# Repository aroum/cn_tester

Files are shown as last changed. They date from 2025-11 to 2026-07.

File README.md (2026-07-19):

# c!n tester: ProMicro-like Microcontroller Tester

## 🚀 Project Overview

The **c!n tester** is a dedicated hardware and software solution designed for automated functional testing of ProMicro-like microcontrollers (MCUs). Its primary goal is to provide a fast and reliable way to verify basic pin connectivity and functionality before deployment.

### 🚧 Current Status: Work In Progress (WIP)

The core testing logic and fundamental functionality are fully operational. However, active development is focused on improving the GUI and enhancing the overall user experience.

> [!IMPORTANT]
> **Bug Reports & Logging:**
> * **Any bug reports must be accompanied by logs.** Reports without logs cannot be diagnosed and will be closed.
> * **How to access logs:** Inside the GUI, click on the **USB connector image** at the center of the pinout visualization. This will open the log view showing real-time console outputs for both Master and Target MCUs.
> * If the application fails to start entirely, look for the `app_error.log` file created in the same directory as the executable.

## 🧱 Hardware System

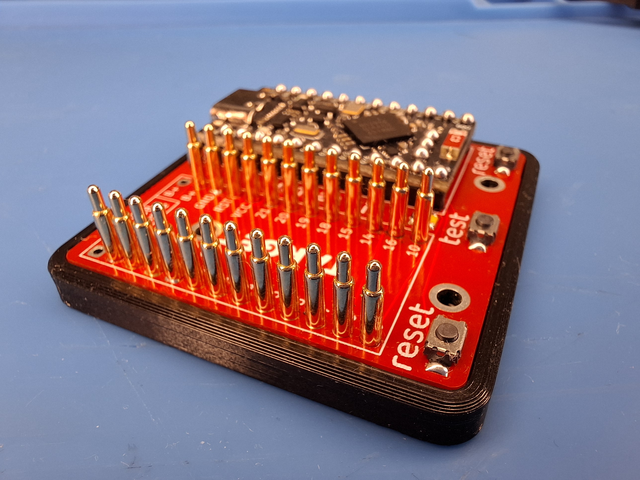
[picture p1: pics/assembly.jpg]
H032


The hardware consists of a custom Printed Circuit Board (PCB) housing two microcontrollers:

1. **Master MCU:** Controls the entire testing process, communicates with the host application, and manages test sequences.

2. **Target MCU:** This is the ProMicro-like microcontroller under test.

Essentially, the PCB represents a direct connection of the pins of the two microcontrollers; the same setup can be achieved using regular wires.

## 💻 Software System

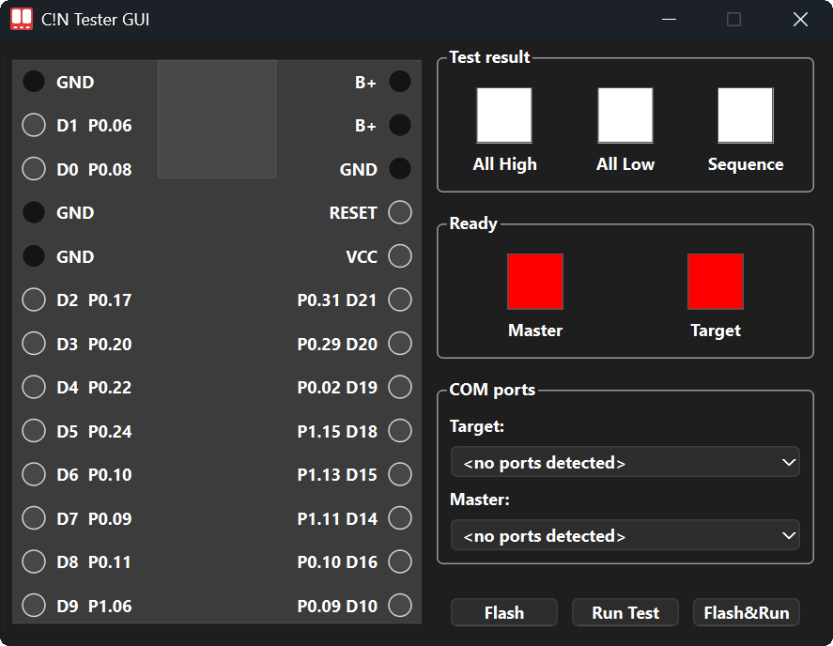
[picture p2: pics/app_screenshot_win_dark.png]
app)win_dark


**Technology Stack:**

* Python 3.10+
* PySide6 — used to create the graphical user interface (GUI).
* Nuitka — used to compile Python code into standalone executable files.
* platformio — used to compile MCU firmware.
* adafruit-nrfutil — used for flashing firmware onto microcontrollers.
* pyserial — provides communication between the computer and microcontrollers via COM ports.

All communication between the host application (software) and the MCUs is conducted via serial ports (COM ports).

Currently, there is no fully developed CLI application, but since both the Target and Master microcontrollers are connected to the computer via COM ports, you can interact with them directly using standard terminal commands.

## ⚙️ Testing Process Details

The system is designed for quick, repeatable functional checks. The Master MCU and the Target MCU communicate over dedicated lines to perform the tests.

### Test Sequence

The system uses an orchestrated handshake process to ensure reliable communication. On power-up, both MCUs send discovery messages. Once the application identifies and initializes the ports, the following sequence is performed under direct application control:

1. **Handshake & Initialization:** The application scans all COM ports (via **Auto Search** or manual selection), identifies the Master and Target, and sends an `INIT` command to synchronize them.

2. **All Pins HIGH:** The application commands both MCUs to enter the `ALL_HIGH` stage. The Target drives all pins HIGH, and the Master verifies the connectivity.

3. **All Pins LOW:** The application commands both MCUs to enter the `ALL_LOW` stage. The Target drives all pins LOW, and the Master verifies the state.

4. **Individual Pin Sequence:** The application orchestrates a per-pin sequence. It commands the Target to toggle a specific pin and then commands the Master to verify that specific pin's state. This step-by-step approach ensures maximum reliability and clear diagnostic feedback.

### Test Indicators

* **GUI Indicators:** The application provides real-time feedback for each test stage (All High, All Low, Sequence).
* **Pinout View:** A dynamic visualization shows exactly which pins passed or failed the test.
* **Master Hardware Button:** You can start the test by pressing the physical button on the Master MCU after it has been initialized by the application.

### Workflow for Testing a New Target

1. Connect the **Master MCU** to the host computer.
2. Open the **c!n tester** application.
3. Connect the new **Target MCU**.
4. Click **"Auto Search"** to automatically find and initialize both MCUs.
5. Click **"Run Test"** in the app OR press the physical **Button** on the Master MCU.
6. Wait for the test completion and observe the results in the Pinout View.
7. Insert a new Target MCU and repeat.

For now, the Master MCU is flashed manually using a uf2 file. Put the MCU into bootloader mode and copy the file to it.

## 📝 Usage Guide

The recommended and simplest way to use the application is by using the **pre-compiled binaries** available in the project's [Releases](https://github.com/aroum/cn_tester/releases/) section.

### 📦 Running Standalone Binaries (Recommended)

1. Download the executable file for your operating system from the project's [Releases](https://github.com/aroum/cn_tester/releases/) page.

2. **For Linux/macOS:** You must grant execution permissions before launching the binary:

   ```bash
   chmod +x cn_tester_app
   ```

3. **For Linux:** To allow the application to access /dev/ttyACM*, you need to add the current user to the dialout group:

   ```bash
   sudo usermod -a -G dialout $USERÍ
   ```

4. Flashing Feature Dependency: If you plan to use the target MCU flashing function, you must have the adafruit-nrfutil utility available on your system. You can ensure this in two ways:
     * Install via Pip : `pip install adafruit-nrfutil`.
     * Local Binary: Download a pre-compiled binary of [adafruit-nrfutil](https://github.com/adafruit/Adafruit_nRF52_nrfutil/releases) from its project releases and place it alongside the C!N tester app executable.
5. Launch the application:
   * **For Linux:** `./cn_tester_app_linux_x64`
   * **macOS:** `./cn_tester_app_macos_aarch64`
   * **Windows:** `cn_tester_win_x64.exe`

> [!TIP]
> To view or copy the logs for debugging, click on the **USB connector image** at the center of the pinout view in the application. See the note on [Bug Reports & Logging](#-project-overview) at the top of this document.

### 🐍 Running from Source (Development)

This method is recommended only for development or if you wish to modify the source code.

#### Prerequisites

Python 3.10 or newer.

#### Dowloand source code

```
git clone https://github.com/aroum/cn_tester.git
```

#### Install Dependencies

```
pip install -r requirements.txt
```

if you use conda:

```
conda install libpython-static
```

#### Execute the Application

```
python main.py
```

### 🏗️ Building Standalone Binaries (Nuitka)

To compile the application into a standalone executable that does not require a local Python 3.10+ environment, use the Nuitka compiler. For details, see the [nuitka documentation](https://nuitka.net/user-documentation/user-manual.html).

#### Dowloand source code

```
git clone https://github.com/aroum/cn_tester.git
```

#### Install dependencies

```
pip install -r requirements_build.txt
```

#### 🍏 macOS Compilation

##### Prerequisites

* [Xcode](https://apps.apple.com/us/app/xcode/id497799835?mt=12)
* [Homebrew](https://brew.sh)

##### Create and activate a clean environment

``` bash
brew install python@3.10 nuitka
python3.10 -m venv /tmp/cleanenv
source /tmp/cleanenv/bin/activate
# source /tmp/cleanenv/bin/activate.fish #for fish
pip install -r requirements_build.txt
```

##### Compilation

``` bash
nuitka  \
   --onefile  \
   --macos-create-app-bundle \
   --macos-app-icon=ICON_PATH \
   --macos-app-name=MACOS_APP_NAME \
   --macos-app-icon=icon/icon.png=icon/icon.png 
   --enable-plugin=pyside6  \
   --include-data-files=icon/icon.png=icon/icon.png \
   --include-data-dir=mcu_firmware=mcu_firmware \
   --include-data-files=mcu_firmware/firmware_target.hex=mcu_firmware/firmware_target.hex \
   --output-dir=build \
   --product-name="C!N Tester GUI" \
   --clean-cache=all \
   --output-filename=cn_tester_app.app \
   main.py
```

#### 🪟 Windows Compilation

##### Prerequisites

* Visual Studio C++ build tools

##### Compilation

``` bash
call "C:\Program Files\Microsoft Visual Studio\2022\BuildTools\VC\Auxiliary\Build\vcvars64.bat"

nuitka ^
  --onefile ^
  --windows-console-mode=disable ^
  --enable-plugin=pyside6 ^
  --windows-icon-from-ico=icon/icon.ico ^
  --include-data-files=icon/icon.png=icon/icon.png ^
  --include-data-dir=mcu_firmware=mcu_firmware ^
  --include-data-files=mcu_firmware/firmware_target.hex=mcu_firmware/firmware_target.hex ^
  --output-dir=build ^
  --product-name="C!N Tester GUI" ^
  --file-version=0.1.0 ^
  --clean-cache=all ^
  --output-filename=cn_tester_app.exe ^
  main.py
```

#### 🐧 Linux Compilation

##### Prerequisites

* python3-dev package
* GCC
* patchelf

##### Compilation  

``` bash
nuitka  \
   --onefile  \
   --enable-plugin=pyside6  \
   --include-data-files=icon/icon.png=icon/icon.png \
   --include-data-dir=mcu_firmware=mcu_firmware \
   --include-data-files=mcu_firmware/firmware_target.hex=mcu_firmware/firmware_target.hex \
   --output-dir=build \
   --product-name="C!N Tester GUI" \
   --clean-cache=all \
   --output-filename=cn_tester_app.bin \
   main.py
```

### 💡 Future Plans

We have several improvements planned for the upcoming sprints:

* Bluetooth Functionality Testing: Planning and implementation of test sequences to verify the basic operation of the Target MCU's Bluetooth features.
* Setup CI/CD with GitHub Actions: Implement GitHub Actions workflows for automated cross-platform compilation of the application binaries and firmware flashing.
* Add some renders of the PCB and case, as well as screenshots of the app.
* Work on the documentation.

### 🙏 Acknowledgements

A special thank you to the following community members:

Compilation & Testing: [@Rowb](https://github.com/Rowb), [@turtle-bazon](https://github.com/turtle-bazon)

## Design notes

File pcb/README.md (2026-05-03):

# Panel

In the panel folder, a 2x2 panel option is available, its size is smaller than 100x100 mm.

# Gerber files

Gerber files can be downloaded in [releases](https://github.com/aroum/cn_tester/releases).

# BOM

| Item |  Qty | Remarks |
| --- | ---: | --- |
| MCU | 2 | target and master |
| [Sockets](https://github.com/joric/nrfmicro/wiki/Sockets) | 12x4 | for MCU |
| SMD button 3x4x2mm | 3 | for reset and start test |
| SMD resistor 0603 1-5k | 1 | |
| SMD LED 0603 | 1 | |

[IBOM](https://htmlpreview.github.io/?https://github.com/aroum/PNCATEHO/blob/master/pcb/cn_tester/ibom/ibom.html)

You can use any sockets for the target microcontroller, but if you want to test the microcontroller without soldering I recommend spring pin headers or pogo pins (H032). When using H032 you will need to press them to ensure good contact.

![spring pin](https://private-user-images.githubusercontent.com/852547/405723092-81f82d2c-c411-478a-a34d-f9249b987f54.jpg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)

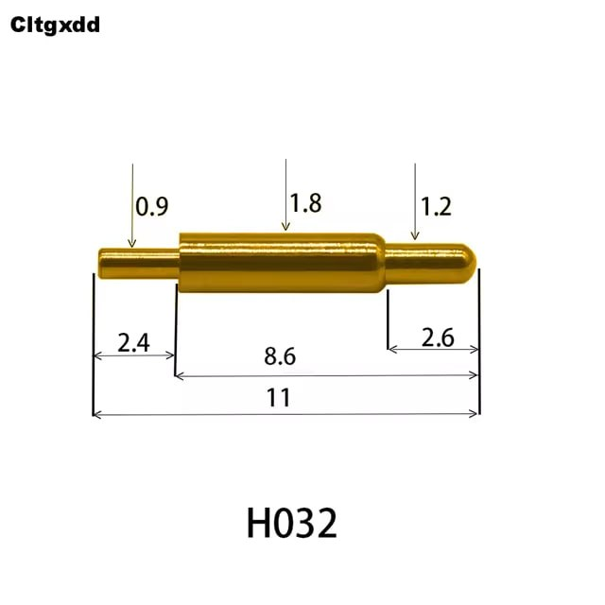
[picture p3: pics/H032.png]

H032

Thanks to [@ShyPsy](https://github.com/ShyPsy) for choosing and testing suitable pogo pins.

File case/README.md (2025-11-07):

# CASE

This case is suitable for installing the board in any direction.

# BOM

* magnets size: 7x2mm (4 pcs)
* bumpons size: 8x2mm (4 pcs)
* nuts size: m2 (4 pcs)
* sqrews size: m2x5 (4 pcs)

STL models can be downloaded in [releases](https://github.com/aroum/cn_tester/releases).

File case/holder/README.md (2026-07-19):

# Holder

A small 3D-printed holder that keeps the target board in place during testing so it doesn't slip off the contacts. Especially useful when the target board already has its pin headers soldered on.

| | |
|---|---|
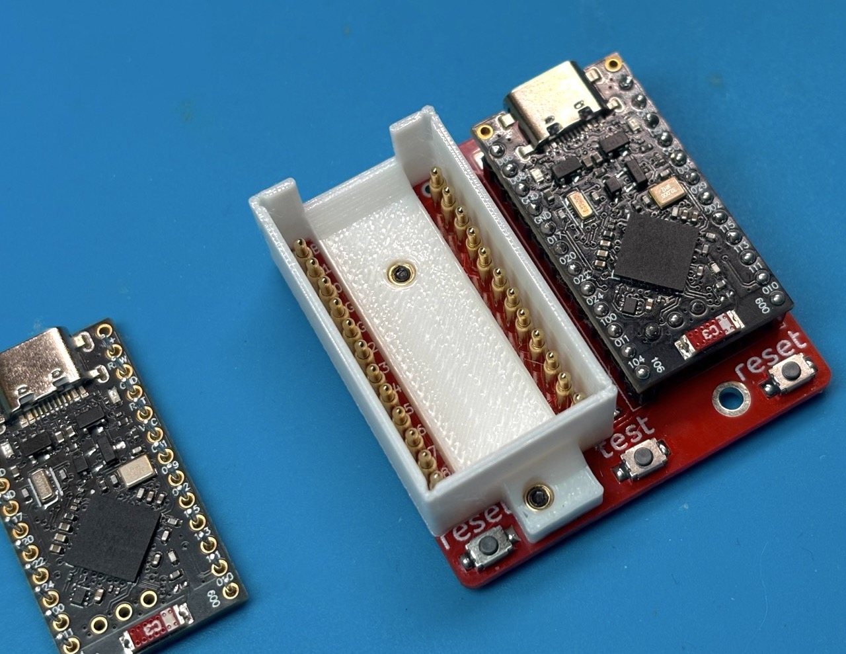
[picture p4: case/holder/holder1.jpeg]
holder
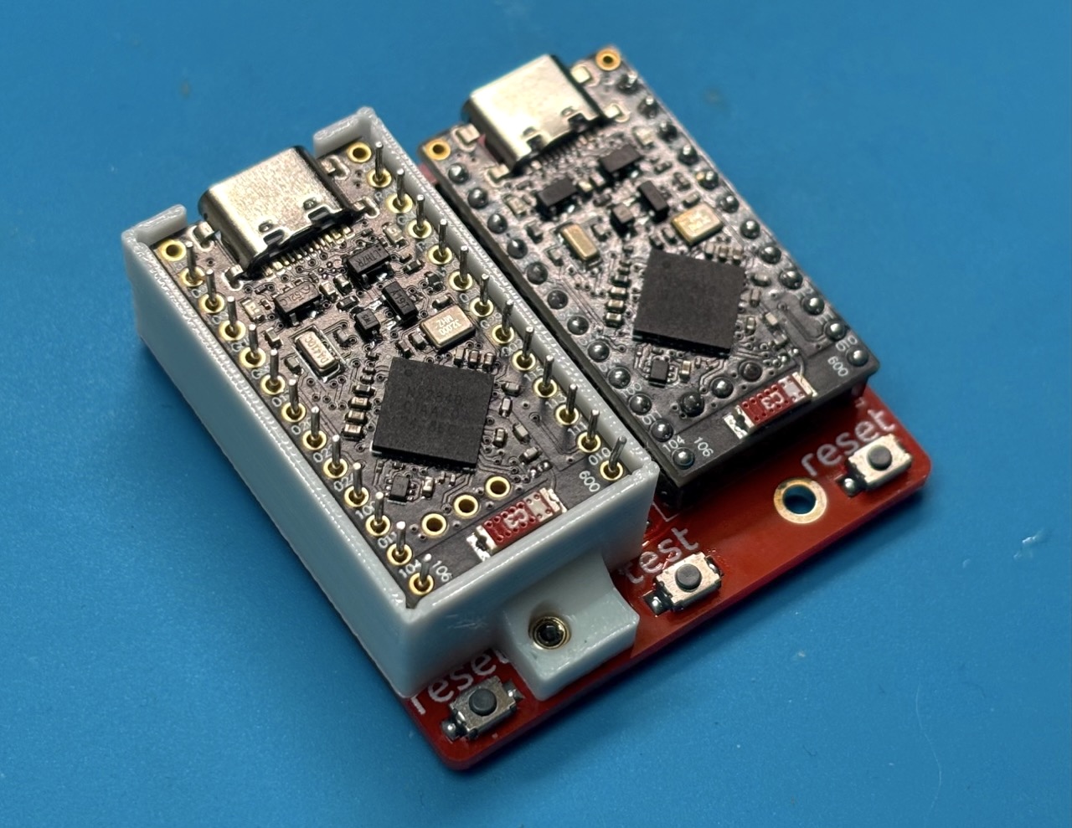
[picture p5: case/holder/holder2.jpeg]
holder in use
|  |  |

## BOM

* screws size: m2x5 (2 pcs)
* brass inserts size: m2x3x3.2 (2 pcs)

## Files

- [holder.step](holder.step) — editable CAD source

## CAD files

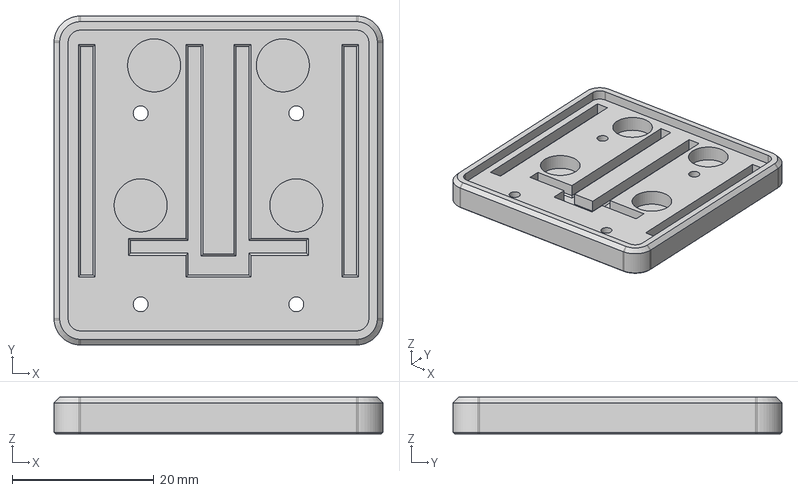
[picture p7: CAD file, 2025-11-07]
case/c!n_tester_case.step
46.5 x 46.5 x 5.19 mm

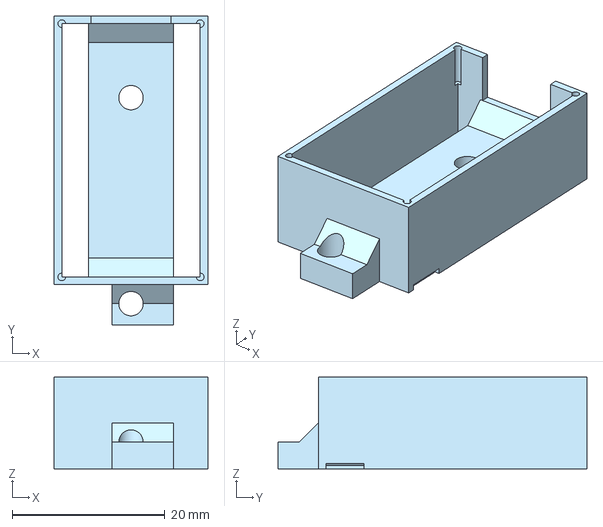
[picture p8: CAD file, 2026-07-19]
case/holder/holder.step
20.2 x 40.5 x 12.0 mm

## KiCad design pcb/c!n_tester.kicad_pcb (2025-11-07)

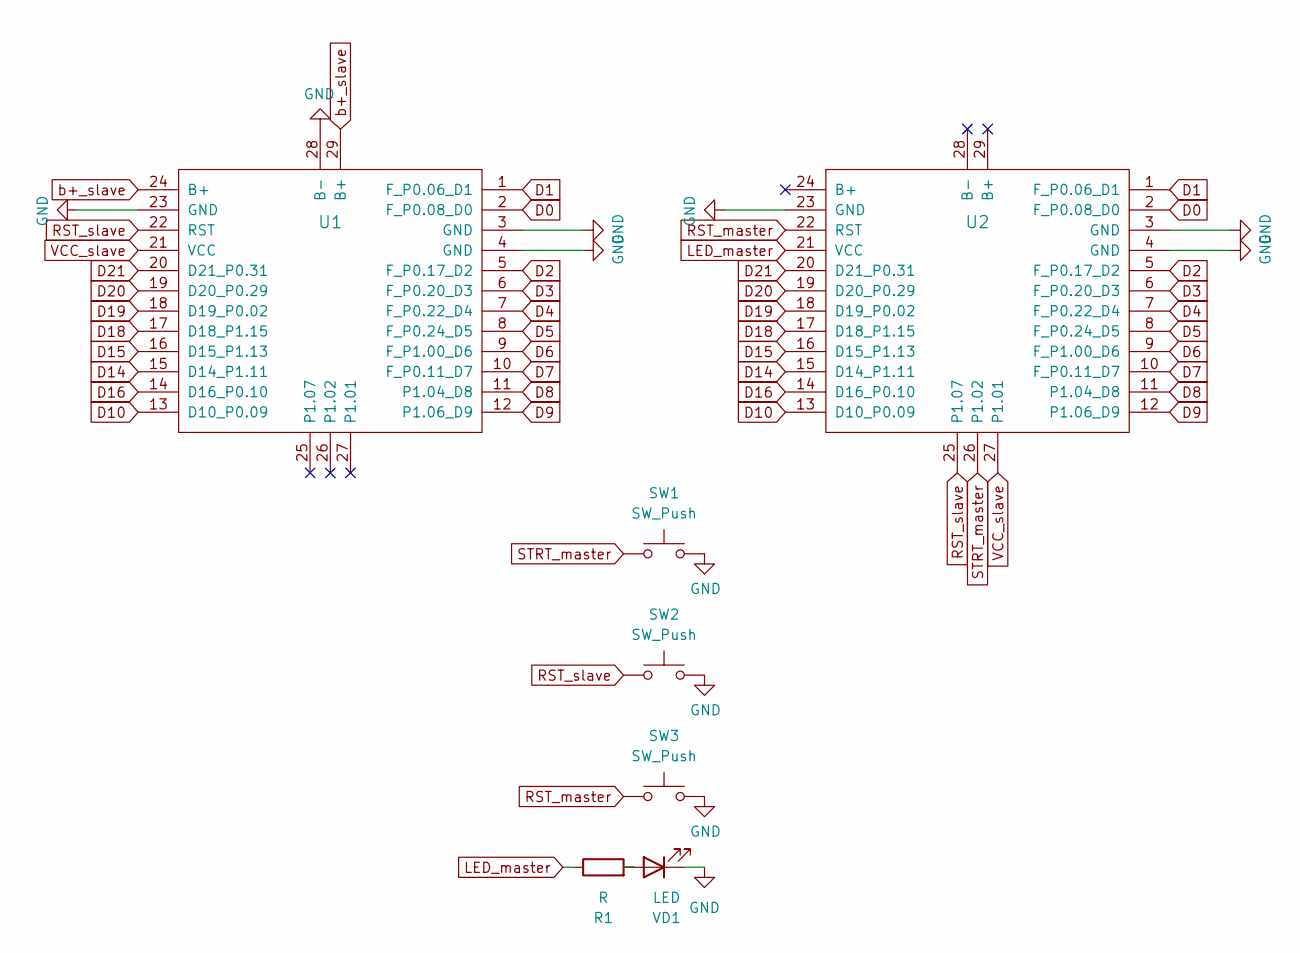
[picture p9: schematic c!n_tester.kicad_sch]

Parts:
R1: R
SW1, SW2, SW3: SW_Push
U1, U2: ProMicro_r; ProMicro_cutout
VD1: LED

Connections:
D0: U1.2 (F_P0.08_D0), U2.2 (F_P0.08_D0)
D1: U1.1 (F_P0.06_D1), U2.1 (F_P0.06_D1)
D2: U1.5 (F_P0.17_D2), U2.5 (F_P0.17_D2)
D3: U1.6 (F_P0.20_D3), U2.6 (F_P0.20_D3)
D4: U1.7 (F_P0.22_D4), U2.7 (F_P0.22_D4)
D5: U1.8 (F_P0.24_D5), U2.8 (F_P0.24_D5)
D6: U1.9 (F_P1.00_D6), U2.9 (F_P1.00_D6)
D7: U1.10 (F_P0.11_D7), U2.10 (F_P0.11_D7)
D8: U1.11 (P1.04_D8), U2.11 (P1.04_D8)
D9: U1.12 (P1.06_D9), U2.12 (P1.06_D9)
D10: U1.13 (D10_P0.09), U2.13 (D10_P0.09)
D14: U1.15 (D14_P1.11), U2.15 (D14_P1.11)
D15: U1.16 (D15_P1.13), U2.16 (D15_P1.13)
D16: U1.14 (D16_P0.10), U2.14 (D16_P0.10)
D18: U1.17 (D18_P1.15), U2.17 (D18_P1.15)
D19: U1.18 (D19_P0.02), U2.18 (D19_P0.02)
D20: U1.19 (D20_P0.29), U2.19 (D20_P0.29)
D21: U1.20 (D21_P0.31), U2.20 (D21_P0.31)
GND: SW1.2, SW2.2, SW3.2, U1.3 (GND), U1.4 (GND), U1.23 (GND), U1.28 (B-), U2.3 (GND), U2.4 (GND), U2.23 (GND), VD1.1 (K)
LED_master: R1.1, U2.21 (VCC)
unnamed: R1.2, VD1.2 (A)
RST_master: SW3.1, U2.22 (RST)
RST_slave: SW2.1, U1.22 (RST), U2.25 (P1.07)
STRT_master: SW1.1, U2.26 (P1.02)
VCC_slave: U1.21 (VCC), U2.27 (P1.01)
b+_slave: U1.24 (B+), U1.29 (B+)

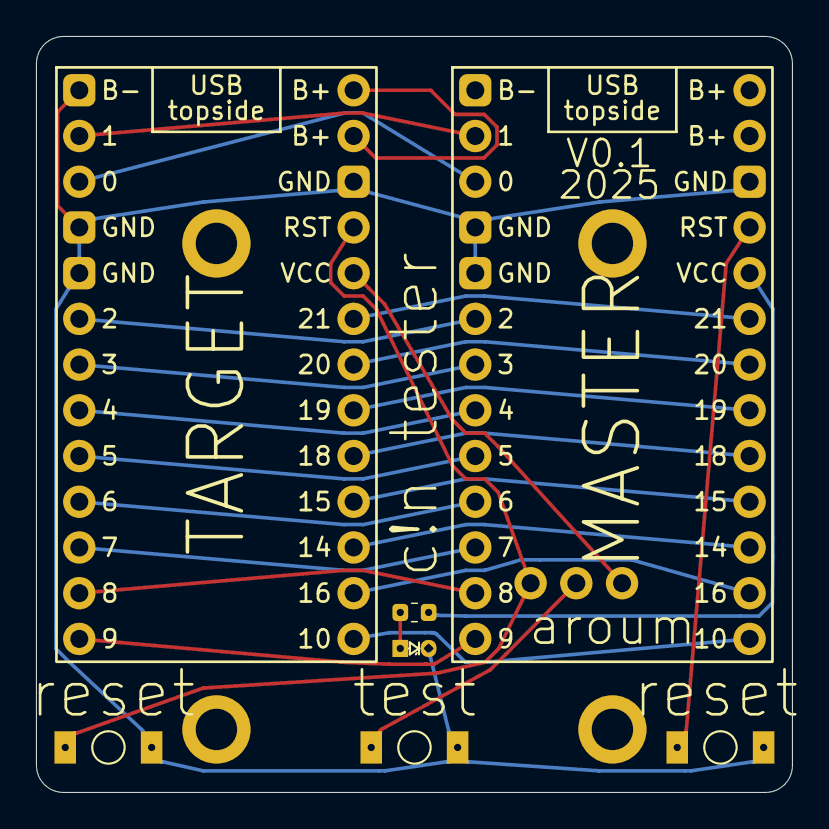
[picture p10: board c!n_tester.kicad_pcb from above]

Board: 2 copper layers, 42.0 x 42.0 mm, 11 parts (1 on the bottom side), 26 nets.

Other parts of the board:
H1, H2, H3, H4: MountingHole; mountingHole_plate

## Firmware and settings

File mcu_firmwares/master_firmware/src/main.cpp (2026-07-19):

// Master firmware for NRF52840 nice!nano: ALL_HIGH -> ALL_LOW -> SEQUENCE
#include <Adafruit_TinyUSB.h>
#include <Arduino.h>
#include <MiniShell.h>

// --- Special pins ---
#define LED_STATUS_PIN P0_15
#define LED_PCB_PIN P0_13
#define BUTTON_PIN P1_02
#define RESET_SENDER_PIN P1_01

// Master reads external Target power on P1_07; Target controls it via P0_13
const int VCC_PIN = P1_07; // Target power monitor

// Dynamic test pins (order is important and synchronized with Target)
const int TEST_PINS[] = {VCC_PIN, // P1_07 (VCC) — externally controlled power,
                                  // checked as a regular line
                         P0_31, P0_29, P0_02, P1_15, P1_13, P1_11, P0_10, P0_09,
                         P1_06, P1_04, P0_11, P1_00, P0_24, P0_22, P0_20, P0_17,
                         P0_08, P0_06};
const int NUM_TEST_PINS = sizeof(TEST_PINS) / sizeof(TEST_PINS[0]);

// Labels for console printing (must match TEST_PINS order)
const char *TEST_LABELS[] = {"P0_13(VCC)", "P0_31", "P0_29", "P0_02", "P1_15",
                             "P1_13",      "P1_11", "P0_10", "P0_09", "P1_06",
                             "P1_04",      "P0_11", "P1_00", "P0_24", "P0_22",
                             "P0_20",      "P0_17", "P0_08", "P0_06"};

// --- Test states ---
enum TestState {
  STATE_HANDSHAKE,
  STATE_WAIT_BUTTON,
  STATE_WAIT_ALL_HIGH,
  STATE_WAIT_ALL_LOW,
  STATE_SEQUENCE,
  STATE_SUCCESS,
  STATE_FAIL
};

// --- Timing parameters ---
const unsigned long DEBOUNCE_MS = 50;

// --- State variables ---
TestState state = STATE_HANDSHAKE;
unsigned long stateStartMs = 0;
unsigned long lastBlinkMs = 0;
unsigned long lastButtonEdgeMs = 0;
bool lastButtonState = HIGH; // INPUT_PULLUP
int expectedIndex = 0;
bool pinWasHigh[NUM_TEST_PINS];
bool precheckAllHighOk = false;
bool precheckAllLowOk = false;
bool startRequested = false; // start command via Serial
bool startAllHighRequested = false;
bool startAllLowRequested = false;
bool startSequenceRequested = false;
bool nextPinRequested = false;

// One-time BEGIN log flags for stages
bool beginAllHighPrinted = false;
bool beginAllLowPrinted = false;
bool beginSequencePrinted = false;
bool beginFailPrinted = false;

void toState(TestState s) {
  state = s;
  stateStartMs = millis();
}

// Initialize serial, pins, and state machine. Prints "Master: READY".
void setup() {
  Serial.begin(115200);
#if defined(USBCON)
  unsigned long t0 = millis();
  while (!Serial && (millis() - t0) < 3000) {
    delay(10);
  }
#endif
  pinMode(LED_STATUS_PIN, OUTPUT);
  pinMode(LED_PCB_PIN, OUTPUT);
  pinMode(BUTTON_PIN, INPUT_PULLUP);
  pinMode(RESET_SENDER_PIN, OUTPUT);
  digitalWrite(RESET_SENDER_PIN, HIGH);
  digitalWrite(LED_STATUS_PIN, LOW);
  digitalWrite(LED_PCB_PIN, LOW);

  // Test inputs
  pinMode(VCC_PIN, INPUT);
  for (int i = 0; i < NUM_TEST_PINS; i++) {
    pinMode(TEST_PINS[i], INPUT);
    pinWasHigh[i] = false;
  }
  toState(STATE_HANDSHAKE);
}

// Pulse reset line low-high to reset Target (100 ms low)
void pulseReset() {
  Serial.println("Master: SENT RESET");
  digitalWrite(RESET_SENDER_PIN, LOW); // drive LOW
  delay(100);                          // pulse duration
  digitalWrite(RESET_SENDER_PIN, HIGH);
}

// Enter DFU mode: double reset pulse. Used by FLASH/DFU command.
void enterFlashMode() {
  Serial.println("Master: FLASH command received.");
  pulseReset();
  delay(500);
  pulseReset();
}

// Main state machine loop: handles serial commands, button, and test stages.
void loop() {
  unsigned long now = millis();

  // Create a buffer for the current scan
  int currentLevels[NUM_TEST_PINS];

  // Serial commands
  if (Serial.available()) {
    String cmd = Serial.readStringUntil('\n');
    cmd.trim();
    if (cmd.equalsIgnoreCase("INIT")) {
      if (state == STATE_HANDSHAKE || state == STATE_WAIT_BUTTON ||
          state == STATE_FAIL || state == STATE_SUCCESS) {
        // pulseReset();
        Serial.println("Master: READY");
        toState(STATE_WAIT_BUTTON);
      }
    } else if (cmd.equalsIgnoreCase("START")) {
      startRequested = true;
      Serial.println("Master: START command received.");
    } else if (cmd.equalsIgnoreCase("START_ALL_HIGH")) {
      startAllHighRequested = true;
    } else if (cmd.equalsIgnoreCase("START_ALL_LOW")) {
      startAllLowRequested = true;
    } else if (cmd.equalsIgnoreCase("START_SEQUENCE")) {
      startSequenceRequested = true;
    } else if (cmd.equalsIgnoreCase("NEXT_PIN")) {
      nextPinRequested = true;
    } else if (cmd.equalsIgnoreCase("FLASH") || cmd.equalsIgnoreCase("DFU")) {
      enterFlashMode();
    }
  }

  // Button handling with debouncing
  bool btn = digitalRead(BUTTON_PIN);
  if (btn != lastButtonState) {
    lastButtonEdgeMs = now;
    lastButtonState = btn;
  }
  bool pressed = (btn == LOW) && (now - lastButtonEdgeMs > DEBOUNCE_MS);

  switch (state) {
  case STATE_HANDSHAKE: {
    if (now - lastBlinkMs >= 200) {
      Serial.println("Hello! I am Master!");
      lastBlinkMs = now;
      digitalWrite(LED_STATUS_PIN, !digitalRead(LED_STATUS_PIN));
    }
  } break;

  case STATE_WAIT_BUTTON: {
    // Blinking indicates idle; awaiting button or START command
    if (now - lastBlinkMs >= 500) {
      Serial.println("Master: STAGE — IDLE: OK");
      lastBlinkMs = now;
      digitalWrite(LED_STATUS_PIN, !digitalRead(LED_STATUS_PIN));
    }
    if (pressed) {
      while (digitalRead(BUTTON_PIN) == LOW) {
        delay(10);
      }
      Serial.println("Master: BUTTON_PRESSED");
    }
    if (startRequested) {
      startRequested = false;
      Serial.println("Master: START");
      precheckAllHighOk = false;
      precheckAllLowOk = false;
      expectedIndex = 0;
      for (int i = 0; i < NUM_TEST_PINS; i++)
        pinWasHigh[i] = false;
      digitalWrite(LED_STATUS_PIN, LOW);
      beginAllHighPrinted = false;
      beginFailPrinted = false;

      // Reset stage requests
      startAllHighRequested = false;
      startAllLowRequested = false;
      startSequenceRequested = false;
      nextPinRequested = false;

      toState(STATE_WAIT_ALL_HIGH);
    }
  } break;

  case STATE_WAIT_ALL_HIGH: {
    // Require: all dynamic lines HIGH (including VCC as a regular line)
    if (!beginAllHighPrinted) {
      Serial.println("Master: STAGE — ALL_HIGH: AWAIT");
      beginAllHighPrinted = true;
    }

    if (startAllHighRequested) {
      startAllHighRequested = false;
      Serial.println("Master: STAGE — ALL_HIGH: BEGIN");

      bool allHigh = true;
      for (int i = 0; i < NUM_TEST_PINS; i++) {
        currentLevels[i] = digitalRead(TEST_PINS[i]);
        if (currentLevels[i] != HIGH)
          allHigh = false;
      }

      if (allHigh) {
        Serial.println("Master: STAGE — ALL_HIGH: OK");
        precheckAllHighOk = true;
        beginAllLowPrinted = false;
        toState(STATE_WAIT_ALL_LOW);
      } else {
        Serial.print("Master: STAGE — ALL_HIGH: ERROR. LOW_PINS: ");
        bool first = true;
        for (int i = 0; i < NUM_TEST_PINS; i++) {
          if (currentLevels[i] == LOW) {
            if (!first)
              Serial.print(", ");
            Serial.print(TEST_LABELS[i]);
            first = false;
          }
        }
        Serial.println();
        beginAllLowPrinted = false;
        toState(STATE_WAIT_ALL_LOW); // continue test regardless
      }
    }
  } break;

  case STATE_WAIT_ALL_LOW: {
    // Require: all dynamic lines LOW (including VCC as a regular line)
    if (!beginAllLowPrinted) {
      Serial.println("Master: STAGE — ALL_LOW: AWAIT");
      beginAllLowPrinted = true;
    }

    if (startAllLowRequested) {
      startAllLowRequested = false;
      Serial.println("Master: STAGE — ALL_LOW: BEGIN");

      bool allLow = true;
      for (int i = 0; i < NUM_TEST_PINS; i++) {
        currentLevels[i] = digitalRead(TEST_PINS[i]);
        if (currentLevels[i] != LOW)
          allLow = false;
      }

      if (allLow) {
        Serial.println("Master: STAGE — ALL_LOW: OK");
        precheckAllLowOk = true;
        beginSequencePrinted = false;
        toState(STATE_SEQUENCE);
      } else {
        Serial.print("Master: STAGE — ALL_LOW: ERROR. HIGH_PINS: ");
        bool first = true;
        for (int i = 0; i < NUM_TEST_PINS; i++) {
          if (currentLevels[i] == HIGH) {
            if (!first)
              Serial.print(", ");
            Serial.print(TEST_LABELS[i]);
            first = false;
          }
        }
        Serial.println();
        beginSequencePrinted = false;
        toState(STATE_SEQUENCE); // continue test regardless
      }
    }
  } break;

  case STATE_SEQUENCE: {
    // Ensure exactly one pin goes HIGH at a time, in strict order
    if (!beginSequencePrinted) {
      Serial.println("Master: STAGE — SEQUENCE: AWAIT");
      beginSequencePrinted = true;
      startSequenceRequested = false;
      nextPinRequested = false;
    }

    if (!startSequenceRequested) {
      break; // Stay in AWAIT until app says start the sequence
    }

    // Inside sequence: wait for NEXT_PIN command for each pin
    if (!nextPinRequested) {
      static unsigned long lastAwaitPrint = 0;
      if (now - lastAwaitPrint > 500) {
        Serial.print("Master: STAGE — SEQUENCE: AWAIT_PIN — ");
        Serial.println(TEST_LABELS[expectedIndex]);
        lastAwaitPrint = now;
      }
      break;
    }

    // NEXT_PIN received: now we check if that pin went high
    int highCount = 0;
    int lastHighIdx = -1;
    for (int i = 0; i < NUM_TEST_PINS; i++) {
      currentLevels[i] = digitalRead(TEST_PINS[i]);
      if (currentLevels[i] == HIGH) {
        highCount++;
        lastHighIdx = i;
      }
    }

    if (highCount > 1) {
      Serial.print("Master: STAGE — SEQUENCE: ERROR. FAIL_PINS: ");
      bool first = true;
      for (int i = 0; i < NUM_TEST_PINS; i++) {
        if (currentLevels[i] == HIGH) {
          if (!first)
            Serial.print(", ");
          Serial.print(TEST_LABELS[i]);
          first = false;
        }
      }
      Serial.println();
      nextPinRequested = false;
      startSequenceRequested = false;
      toState(STATE_FAIL);
      break;
    }

    if (highCount == 1) {
      nextPinRequested = false; // consume command
      Serial.print("Master: STAGE — SEQUENCE: OK — ");
      Serial.println(TEST_LABELS[lastHighIdx]);

      if (lastHighIdx == expectedIndex) {
        expectedIndex++;
        if (expectedIndex == NUM_TEST_PINS) {
          Serial.println("Master: STAGE — SEQUENCE: ALL OK");
          digitalWrite(LED_STATUS_PIN, HIGH);
          startSequenceRequested = false;
          toState(STATE_SUCCESS);
        }
      } else {
        Serial.print("Master: STAGE — SEQUENCE: ERROR. THE ORDER OF SEQUENCE "
                     "IS VIOLATED. EXPECTED: ");
        Serial.print(TEST_LABELS[expectedIndex]);
        Serial.print(", RECEIVED ");
        Serial.println(TEST_LABELS[lastHighIdx]);
        startSequenceRequested = false;
        toState(STATE_FAIL);
      }
    } else {
      // highCount == 0: wait or timeout
      if (now - stateStartMs > 5000) { // 5s timeout per pin
        Serial.print("Master: STAGE — SEQUENCE: ERROR. TIMEOUT. EXPECTED: ");
        Serial.println(TEST_LABELS[expectedIndex]);
        nextPinRequested = false;
        startSequenceRequested = false;
        toState(STATE_FAIL);
      }
    }
  } break;

  case STATE_SUCCESS: {
    // Steady LED — success; wait for new button press
    Serial.print("Master: STAGE — SUCCESS: OK\n");
    toState(STATE_WAIT_BUTTON);
  } break;

  case STATE_FAIL: {
    // Fast blinking — failure; wait for button
    if (!beginFailPrinted) {
      Serial.println("Master: FAIL");
      beginFailPrinted = true;
    }
    if (now - lastBlinkMs >= 150) {
      lastBlinkMs = now;
      digitalWrite(LED_STATUS_PIN, !digitalRead(LED_STATUS_PIN));
    }
    if (pressed || startRequested) {
      if (pressed) {
        while (digitalRead(BUTTON_PIN) == LOW) {
          delay(10);
        }
      }
      startRequested = false;
      Serial.println("Master: START");
      // pulseReset();
      expectedIndex = 0;
      for (int i = 0; i < NUM_TEST_PINS; i++)
        pinWasHigh[i] = false;
      digitalWrite(LED_STATUS_PIN, LOW);
      // Reset preparatory flags and BEGIN markers
      precheckAllHighOk = false;
      precheckAllLowOk = false;
      beginAllHighPrinted = false;
      beginAllLowPrinted = false;
      beginSequencePrinted = false;
      beginFailPrinted = false;

      startAllHighRequested = false;
      startAllLowRequested = false;
      startSequenceRequested = false;
      nextPinRequested = false;

      toState(STATE_WAIT_ALL_HIGH);
    }
  } break;
  }
}

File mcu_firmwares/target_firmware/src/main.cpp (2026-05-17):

/**
 * Target firmware for nRF52840.
 *
 * Drives the test harness through three stages:
 * 1) ALL_HIGH — drive all pins HIGH.
 * 2) ALL_LOW  — drive all pins LOW.
 * 3) SEQUENCE — toggle each pin HIGH/LOW.
 *
 * Each stage is triggered by an app command.
 */
#include <Adafruit_TinyUSB.h>
#include <Arduino.h>
#include <MiniShell.h>

#define LED_STATUS_PIN P0_15 // status LED
#define VCC_CTRL_PIN P0_13   // Target controls external power

// Dynamic lines (exact same order as Master TEST_PINS)
const int TEST_PINS[] = {VCC_CTRL_PIN, // P0_13 (VCC)
                         P0_31,        P0_29, P0_02, P1_15, P1_13, P1_11,
                         P0_10,        P0_09, P1_06, P1_04, P0_11, P1_00,
                         P0_24,        P0_22, P0_20, P0_17, P0_08, P0_06};
const int NUM_TEST_PINS = sizeof(TEST_PINS) / sizeof(TEST_PINS[0]);

// Protocol timings
const int SEQ_MS = 150; // duration for each pin in sequence

enum State { STATE_HANDSHAKE, STATE_IDLE };

State state = STATE_HANDSHAKE;
unsigned long lastBlinkMs = 0;

void setAll(int level) {
  for (int i = 0; i < NUM_TEST_PINS; i++) {
    digitalWrite(TEST_PINS[i], level);
  }
}

void setup() {
  Serial.begin(115200);
#if defined(USBCON)
  unsigned long t0 = millis();
  while (!Serial && (millis() - t0) < 3000) {
    delay(10);
  }
#endif

  pinMode(LED_STATUS_PIN, OUTPUT);
  digitalWrite(LED_STATUS_PIN, LOW);

  pinMode(VCC_CTRL_PIN, OUTPUT);
  digitalWrite(VCC_CTRL_PIN, LOW);

  for (int i = 0; i < NUM_TEST_PINS; i++) {
    pinMode(TEST_PINS[i], OUTPUT);
    digitalWrite(TEST_PINS[i], LOW);
  }
}

void loop() {
  unsigned long now = millis();
  static int seqIndex = 0;

  if (Serial.available()) {
    String cmd = Serial.readStringUntil('\n');
    cmd.trim();

    if (cmd.equalsIgnoreCase("INIT")) {
      state = STATE_IDLE;
      Serial.println("Target: READY");
      digitalWrite(LED_STATUS_PIN, LOW);
    } else if (cmd.equalsIgnoreCase("START_ALL_HIGH")) {
      state = STATE_IDLE; // auto-transition if INIT was missed
      Serial.println("Target: STAGE — ALL_HIGH: BEGIN");
      setAll(HIGH);
      digitalWrite(LED_STATUS_PIN, HIGH);
      Serial.println("Target: STAGE — ALL_HIGH: OK");
    } else if (cmd.equalsIgnoreCase("START_ALL_LOW")) {
      state = STATE_IDLE;
      Serial.println("Target: STAGE — ALL_LOW: BEGIN");
      setAll(LOW);
      digitalWrite(LED_STATUS_PIN, LOW);
      Serial.println("Target: STAGE — ALL_LOW: OK");
    } else if (cmd.equalsIgnoreCase("START_SEQUENCE")) {
      state = STATE_IDLE;
      Serial.println("Target: STAGE — SEQUENCE: BEGIN");
      seqIndex = 0;
    } else if (cmd.equalsIgnoreCase("NEXT_PIN")) {
      state = STATE_IDLE;
      if (seqIndex < NUM_TEST_PINS) {
        digitalWrite(TEST_PINS[seqIndex], HIGH);
        delay(SEQ_MS);
        digitalWrite(TEST_PINS[seqIndex], LOW);
        seqIndex++;
        if (seqIndex == NUM_TEST_PINS) {
          Serial.println("Target: STAGE — SEQUENCE: ALL OK");
        }
      }
    }
  }

  if (state == STATE_HANDSHAKE) {
    if (now - lastBlinkMs >= 200) {
      Serial.println("Hello! I am Target!");
      lastBlinkMs = now;
      digitalWrite(LED_STATUS_PIN, !digitalRead(LED_STATUS_PIN));
    }
  } else {
    // Heartbeat
    if (now - lastBlinkMs >= 500) {
      Serial.println("Target: STAGE — IDLE: OK");
      lastBlinkMs = now;
    }
  }
}

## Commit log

2025-11-07 Initial project structure and core files added
    Added application source files, firmware, hardware case, and PCB design files. Updated README with detailed documentation and usage instructions. Included .gitignore for common build and environment 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
    [c!n_tester.kicad_pcb, c!n_tester.kicad_sch, c!n_tester_case.step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]
2025-11-08 Add dark mode app screenshot to README
    Inserted a new screenshot (app_screenshot_win_dark.png) into the README to showcase the application's appearance in Windows dark mode.
2025-11-18 Fix line continuation for Nuitka build on Windows
    Replaces backslashes with backticks for line continuation in the Nuitka build command on Windows to ensure proper execution in PowerShell.
2026-05-06 Refactor pin state handling in main loop
    Refactor state machine logic to use a buffer for current pin levels and improve error reporting for dynamic pin states.
    [main.cpp]
2026-05-06 Revert "Refactor pin state handling in main loop"
    This reverts commit e9a28d489d1da55b9b23fc83d77d5c65b24e0e57.
    [main.cpp]
2026-05-07 Cache pin reads and inline pin-printing
    Introduce a currentLevels scan buffer to avoid repeated digitalRead calls each loop and remove the printDynamicPinsByLevel helper. Inline printing of LOW/HIGH pin lists where needed, rename highIdx to lastHighIdx, and update sequence logic to use the scan buffer for edge detection and pinWasHigh tracking. Minor message wording fixes and streamlined state transitions; overall reduces I/O overhead and simplifies the per-stage checks.
    [main.cpp]
2026-05-08 Add nice!nano boards and CI for firmwares
    Add nice!nano board definitions and variant sources for both master_firmware and target_firmware (boards/nicenano.json, variant.cpp, variant.h). Update each platformio.ini to use env supermini, set src_dir and board_build.variants_dir, and add Adafruit nRF52 dependency. Replace CI steps: rename workflow, remove nicenano-example clone, download UF2 utilities once, build master and target firmware directories, convert HEX to UF2 for each, and upload separate ZIP/UF2 artifacts.
    [variant.h]
2026-05-08 Use P0_xx/P1_xx pin macro names
    Replace numeric PIN_### macros with explicit P0_xx / P1_xx names in nicenano variant headers for both master and target firmware. This clarifies port/bit mapping (P0.02..P0.31 and P1.00..P1.15) and standardizes naming across boards. Files changed: mcu_firmwares/master_firmware/boards/nicenano/variant.h and mcu_firmwares/target_firmware/boards/nicenano/variant.h. Note: LED_BUILTIN still references PIN_015 and may need to be updated to the new macro (P0_15) in a follow-up.
    [variant.h]
2026-05-08 Update workflows and increase hold timings
    Rename CI workflow entries and tighten firmware triggers, and lengthen MCU hold timings.
    - .github/workflows/build_app.yml: changed workflow name to "Build App (Nuitka)".
    - .github/workflows/build_fw.yml: renamed to "Build Firmware (PlatformIO for n!n_v2)" and updated triggers to manual dispatch and tag-based pushes (v*), replacing the previous push/pull_request triggers.
    - mcu_firmwares/target_firmware/src/main.cpp: increased HOLD_ALL_HIGH_MS and HOLD_ALL_LOW_MS from 1000ms to 2500ms to give the master more time to sample during the protocol.
    These changes make firmware builds run on explicit releases/manual runs and improve timing reliability fo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
    [main.cpp]
2026-05-10 Add MCU handshake, auto-search and protocol control
    Implement end-to-end handshake and command-driven test orchestration: add serial port auto-discovery (discover_mcu_ports) and an "Auto Search" UI button that initializes Master/Target combos and rest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
2026-05-10 Sync INIT/READY flow and UI readiness handling
    Make the UI and firmwares more robust around INIT/READY/start sequencing. UI: add _master_ready/_target_ready and _last_action flags, send INIT to both devices on Run, wait for both READY before issuing START, reset ready indicators on Hello messages, improve auto-search logging and only restart readers when a port was found, and make device combo matching case-insensitive/trimmed. Master firmware: increase reset pulse spacing, accept INIT from more states (allowing recovery from WAIT_BUTTON/FAIL/SUCCESS) and avoid an extra reset pulse on START. Target firmware: always transition to IDLE and respond READY on INIT, and auto-transition to IDLE on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
    [main.cpp, ui.py]
2026-05-17 fix SS pin
2026-06-02 app: fix pin name
    [ui.py]
2026-06-16 case: add target board holder
    [holder.step]
2026-07-19 Rename HEX files and add firmware artifact uploads
    Updates the build workflow to explicitly copy and rename firmware HEX files for clarity, then uploads them as separate artifacts. Also corrects the VCC pin label from P1_07 to P0_13 in the master firmware.
    [main.cpp]
